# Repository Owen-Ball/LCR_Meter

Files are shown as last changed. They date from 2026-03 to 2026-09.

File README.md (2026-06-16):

A DIY LCR meter capable of

1pF to 10mF
1uH to 100H
1mΩ to 1MΩ

(actual ranges to be confirmed)

Many thanks to the work of WeTec/wschuma. Much of the audio codec design and firmware was based on their work on EEVblog and Github
https://www.eevblog.com/forum/projects/teensylcr-a-teensy-based-diy-lcr-meter/
https://github.com/wschuma/TeensyLCR

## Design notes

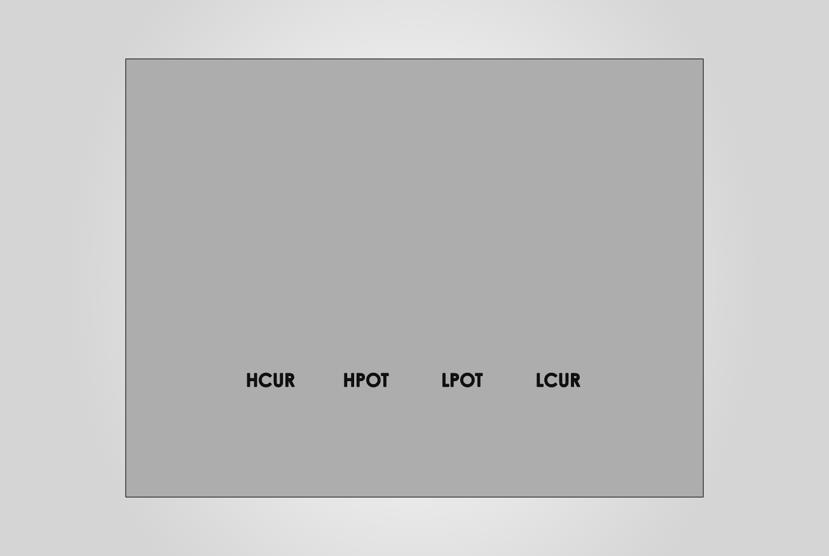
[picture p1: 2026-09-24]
CAD/STLs/front_panel.PNG

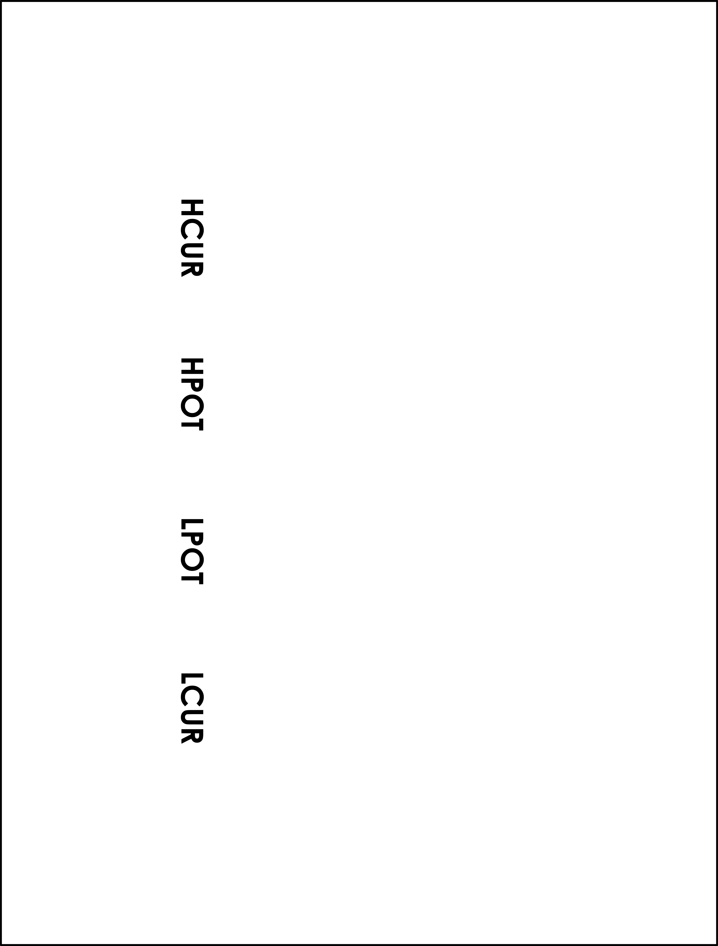
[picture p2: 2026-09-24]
CAD/STLs/bitmap.png

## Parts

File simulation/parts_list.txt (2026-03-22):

THS4561 - diff amps for driving ADCs
TLV354 - Signal buffer and TIA
OPA365 - PGA

To Do
-resistor sizing for PGA
-sim PGA
-add second diff amp
-stability at 100k?

-protection circuit
-power

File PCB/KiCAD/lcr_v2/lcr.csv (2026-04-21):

Reference | Qty | Value | DNP | Exclude from BOM | Exclude from Board | Footprint | Datasheet
BZ1 | 1 | Buzzer |  |  |  | Buzzer_Beeper:Buzzer_12x9.5RM7.6
C1,C2,C16,C17,C20,C21,C22,C24,C25,C26 | 10 | C |  |  |  | Capacitor_SMD:C_0805_2012Metric
C3,C4,C28,C29 | 4 | 470p |  |  |  | Capacitor_SMD:C_0805_2012Metric
C5,C30 | 2 | 2.7n |  |  |  | Capacitor_SMD:C_0805_2012Metric
C6,C9,C47,C49 | 4 | 1u |  |  |  | Capacitor_SMD:C_0805_2012Metric
C7,C8,C46,C48 | 4 | .1u |  |  |  | Capacitor_SMD:C_0805_2012Metric
C10,C27,C34,C35,C36,C37,C38,C39,C40,C41,C42,C43,C45,C50,C51 | 15 | 100n |  |  |  | Capacitor_SMD:C_0805_2012Metric
C11,C13,C31 | 3 | 100p |  |  |  | Capacitor_SMD:C_0805_2012Metric
C12 | 1 | 220p |  |  |  | Capacitor_SMD:C_0805_2012Metric
C14,C15 | 2 | 33p |  |  |  | Capacitor_SMD:C_0805_2012Metric
C18,C19,C23,C44 | 4 | 47u |  |  |  | Capacitor_SMD:CP_Elec_5x5.9
C33 | 1 | 10u |  |  |  | Capacitor_SMD:C_0805_2012Metric
D3,D4,D5 | 3 | D_Schottky |  |  |  | Diode_SMD:Nexperia_CFP3_SOD-123W
D6 | 1 | D_Schottky |  |  |  | Diode_SMD:D_0805_2012Metric
D8,D9,D10,D11 | 4 | ESD7205 |  |  |  | Package_TO_SOT_SMD:SOT-323_SC-70
F1,F2,F3,F4 | 4 | 1206L012WR |  |  |  | Fuse:Fuse_1206_3216Metric
J1,J2,J3,J4 | 4 | Conn_Coaxial |  |  |  | Connector_Coaxial:BNC_Amphenol_B6252HB-NPP3G-50_Horizontal
J5 | 1 | Conn_01x06_Pin |  |  |  | Connector_PinHeader_2.54mm:PinHeader_1x06_P2.54mm_Vertical
J6 | 1 | Screw_Terminal_01x02 |  |  |  | TerminalBlock_Phoenix:TerminalBlock_Phoenix_MKDS-1,5-2-5.08_1x02_P5.08mm_Horizontal
J7 | 1 | Barrel_Jack_Switch |  |  |  | Connector_BarrelJack:BarrelJack_GCT_DCJ200-10-A_Horizontal
J8 | 1 | Conn_01x09_Pin |  |  |  | Connector_PinHeader_2.54mm:PinHeader_1x09_P2.54mm_Vertical
J9 | 1 | Conn_01x14_Pin |  |  |  | Connector_PinHeader_2.54mm:PinHeader_1x14_P2.54mm_Vertical
J10 | 1 | Conn_01x02_Pin |  |  |  | Connector_PinHeader_2.54mm:PinHeader_1x02_P2.54mm_Vertical
JP1 | 1 | Jumper_2_Open |  |  |  | Connector_PinHeader_2.54mm:PinHeader_1x02_P2.54mm_Vertical
Q1,Q2 | 2 | DMG1012UWQ-7 |  |  |  | Package_TO_SOT_SMD:SOT-323_SC-70
R1,R8,R21,R24,R44,R48 | 6 | 8.2k |  |  |  | Resistor_SMD:R_0805_2012Metric
R2,R7,R45,R49 | 4 | 1.6k |  |  |  | Resistor_SMD:R_0805_2012Metric
R3,R6,R46,R50 | 4 | 300 |  |  |  | Resistor_SMD:R_0805_2012Metric
R4,R5,R31,R35,R47,R51,R60,R63,R64 | 9 | 100 |  |  |  | Resistor_SMD:R_0805_2012Metric
R9,R10,R17,R41 | 4 | 1M |  |  |  | Resistor_SMD:R_0805_2012Metric
R13,R14,R15,R30,R34,R36,R42,R52,R53,R54,R55 | 11 | 1k |  |  |  | Resistor_SMD:R_0805_2012Metric
R16,R18,R56,R57 | 4 | 22 |  |  |  | Resistor_SMD:R_0805_2012Metric
R19,R20 | 2 | 5.1k |  |  |  | Resistor_SMD:R_0805_2012Metric
R22,R23,R29,R37,R43,R58,R59,R61,R62,R65 | 10 | 10k |  |  |  | Resistor_SMD:R_0805_2012Metric
R25,R26 | 2 | 3.3k |  |  |  | Resistor_SMD:R_0805_2012Metric
R27,R32,R33,R39,R40 | 5 | R_US |  |  |  | Resistor_SMD:R_0805_2012Metric
R28,R38 | 2 | 100k |  |  |  | Resistor_SMD:R_0805_2012Metric
R66 | 1 | 0 |  |  |  | Resistor_SMD:R_0805_2012Metric
SW1 | 1 | SW_SPST |  |  |  | Connector_PinHeader_2.54mm:PinHeader_1x02_P2.54mm_Vertical
TP1,TP2,TP3,TP4,TP5,TP6,TP7,TP8,TP9,TP10,TP11,TP12,TP13,TP14,TP15,TP16 | 16 | TestPoint |  |  |  | Others:testpoint_0805
U1,U13 | 2 | OPA2365AIDR |  |  |  | Package_SO:SOIC-8_3.9x4.9mm_P1.27mm
U2,U15 | 2 | THS4561IDGKR |  |  |  | Package_SO:TSSOP-8_3x3mm_P0.65mm | https://www.ti.com/lit/ds/symlink/ths4561.pdf?HQS=dis-dk-null-digikeymode-dsf-pf-null-wwe&ts=1774136984154
U3 | 1 | CS4272 |  |  |  | Package_SO:TSSOP-28_4.4x9.7mm_P0.65mm | https://statics.cirrus.com/pubs/proDatasheet/CS4272_F1.pdf
U4,U14 | 2 | DG4052EEQ |  |  |  | Package_SO:TSSOP-16_4.4x5mm_P0.65mm
U5 | 1 | Teensy4.1_mainpins |  |  |  | Teensy:Teensy41_mainpins
U6 | 1 | MCP9800Ax-xOT |  |  |  | Package_TO_SOT_SMD:SOT-23-5 | https://ww1.microchip.com/downloads/aemDocuments/documents/OTH/ProductDocuments/DataSheets/21909d.pdf
U7,U16 | 2 | TLV9161IDBVR |  |  |  | Package_TO_SOT_SMD:SOT-23-5
U9,U12 | 2 | DG2034EDQ |  |  |  | Others:MSOP-10_largecorner
U10,U11 | 2 | MC7805 |  |  |  | Package_TO_SOT_SMD:TO-252-2 | http://www.st.com/content/ccc/resource/technical/document/datasheet/41/4f/b3/b0/12/d4/47/88/CD00000444.pdf/files/CD00000444.pdf/jcr:content/translations/en.CD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
U17 | 1 | TLV9162IDR |  |  |  | Package_SO:SOIC-8_3.9x4.9mm_P1.27mm
Y1 | 1 | Crystal |  |  |  | Crystal:Crystal_SMD_ECS_CSM3X-2Pin_7.6x4.1mm

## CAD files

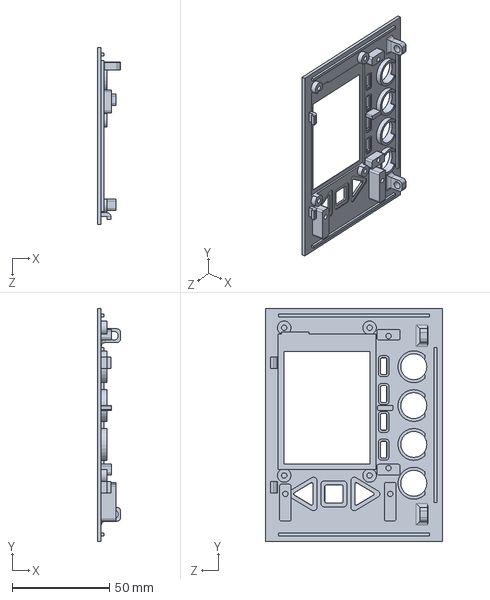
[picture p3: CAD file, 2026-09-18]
CAD/laser_assembly.SLDASM
12.0 x 120.0 x 91.0 mm

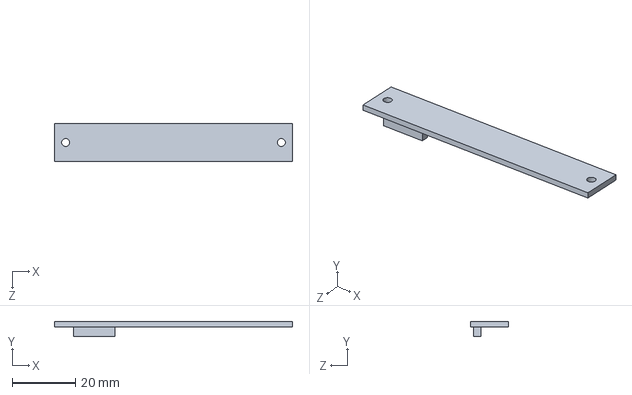
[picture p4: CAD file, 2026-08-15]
CAD/menu_assembly/menu_PCB.SLDPRT
75.0 x 4.60 x 12.0 mm

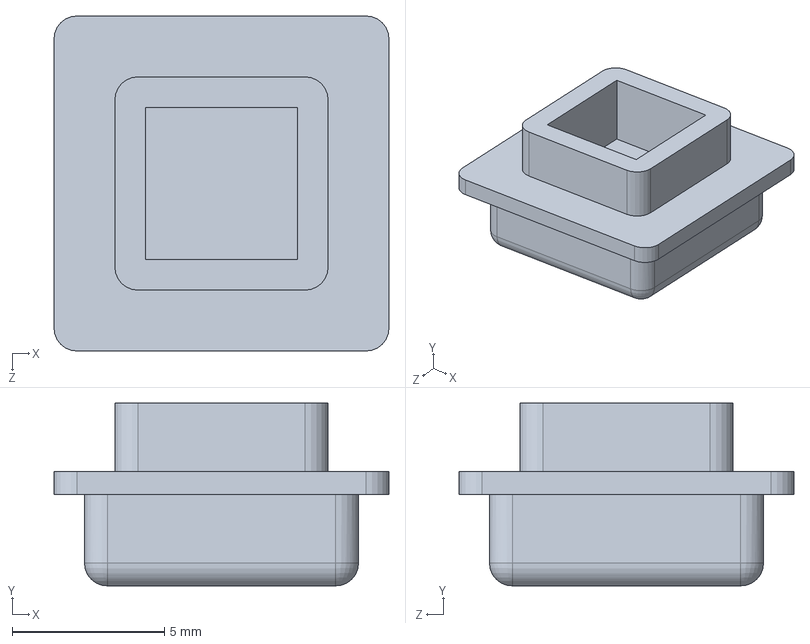
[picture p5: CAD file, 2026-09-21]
CAD/selector_assembly/enter_cap.SLDPRT
11.0 x 6.00 x 11.0 mm

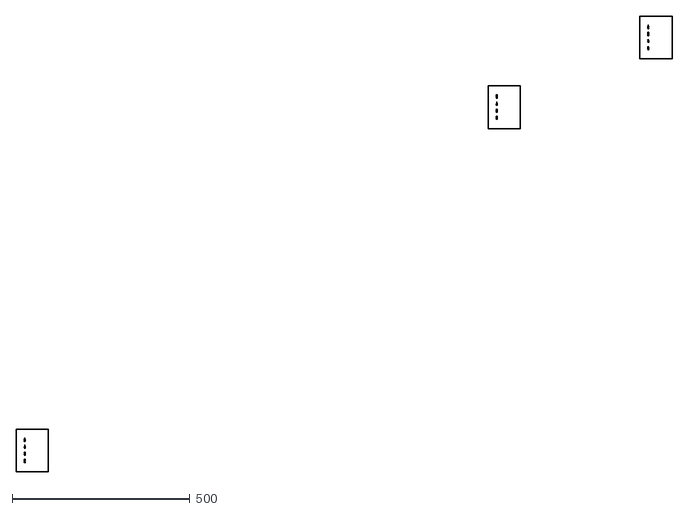
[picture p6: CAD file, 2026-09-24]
CAD/STLs/front_panel2.dxf
1845.1 x 1281.0

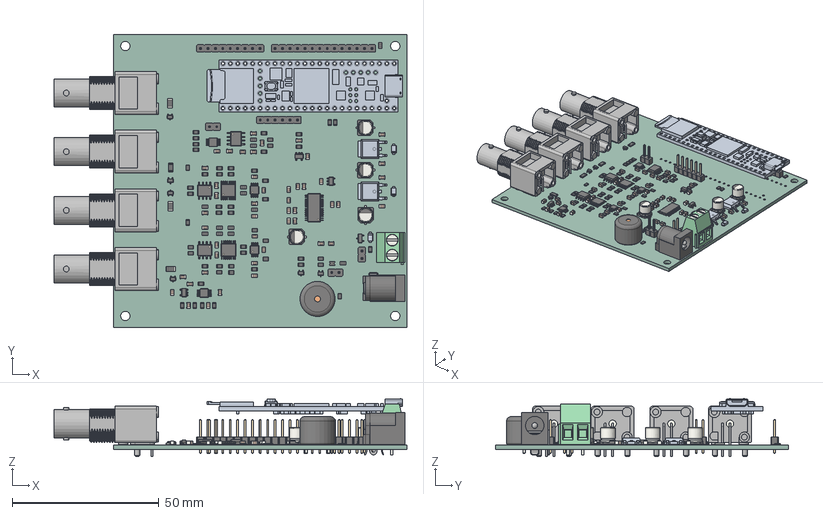
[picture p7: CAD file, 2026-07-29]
PCB/KiCAD/lcr_v2/.step
120.3 x 100.0 x 19.9 mm
R_0805_2012Metric x 65
C_0805_2012Metric x 47
SOT-23-5 x 3
TerminalBlock_Phoenix_MKDS-1,5-2-5.08_1x02_P5.08mm_Horizontal
TSSOP-8_3x3mm_P0.65mm x 2
PinHeader_1x06_P2.54mm_Vertical
.step 1.20.1 x 2
BNC_Amphenol_B6252HB-NPP3G-50_Horizontal x 4
BarrelJack_GCT_DCJ200-10-A_Horizontal
SOT-323_SC-70 x 6
PinHeader_1x02_P2.54mm_Vertical x 3
TSSOP-28_4.4x9.7mm_P0.65mm
.step 1.35.1 x 3
CP_Elec_5x5.9 x 4
Teensy_4.1_Assembly
MSOP-10_3x3mm_P0.5mm x 2
TSSOP-16_4.4x5mm_P0.65mm x 2
SOT-23
SOIC-8_3.9x4.9mm_P1.27mm x 3
D_0805_2012Metric
Fuse_1206_3216Metric x 4
Buzzer_12x9.5RM7.6
PinHeader_1x09_P2.54mm_Vertical
PinHeader_1x14_P2.54mm_Vertical
lcr_PCB

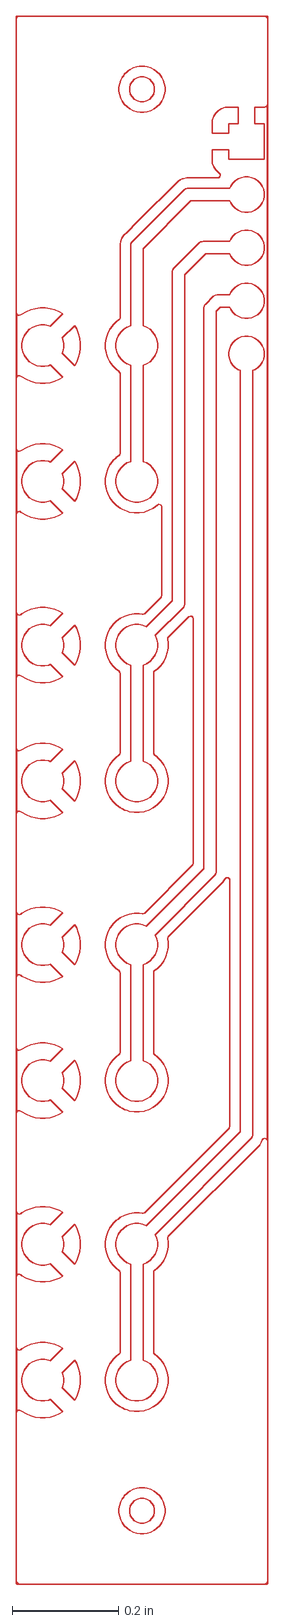
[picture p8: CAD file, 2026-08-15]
PCB/KiCAD/menu_board/menu_board/menu_board-F_Cu.dxf
0.473 x 2.95 in

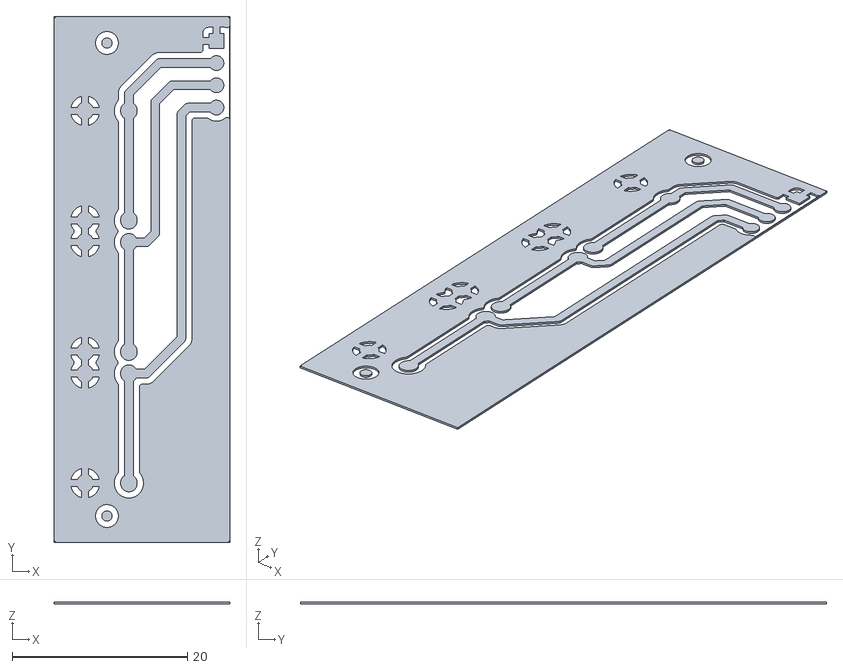
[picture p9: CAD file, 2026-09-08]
PCB/KiCAD/selector_board/selector_board/selector_board.stl
20.1 x 60.0 x 0.2

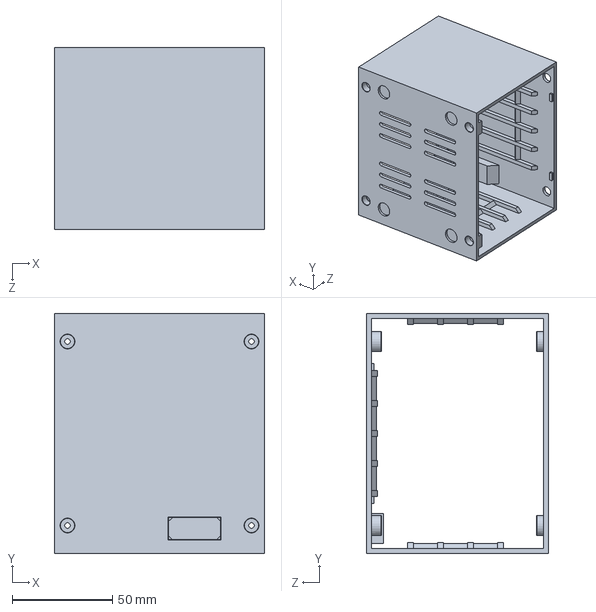
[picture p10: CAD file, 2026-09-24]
CAD/shell.SLDPRT
105.0 x 120.0 x 91.0 mm

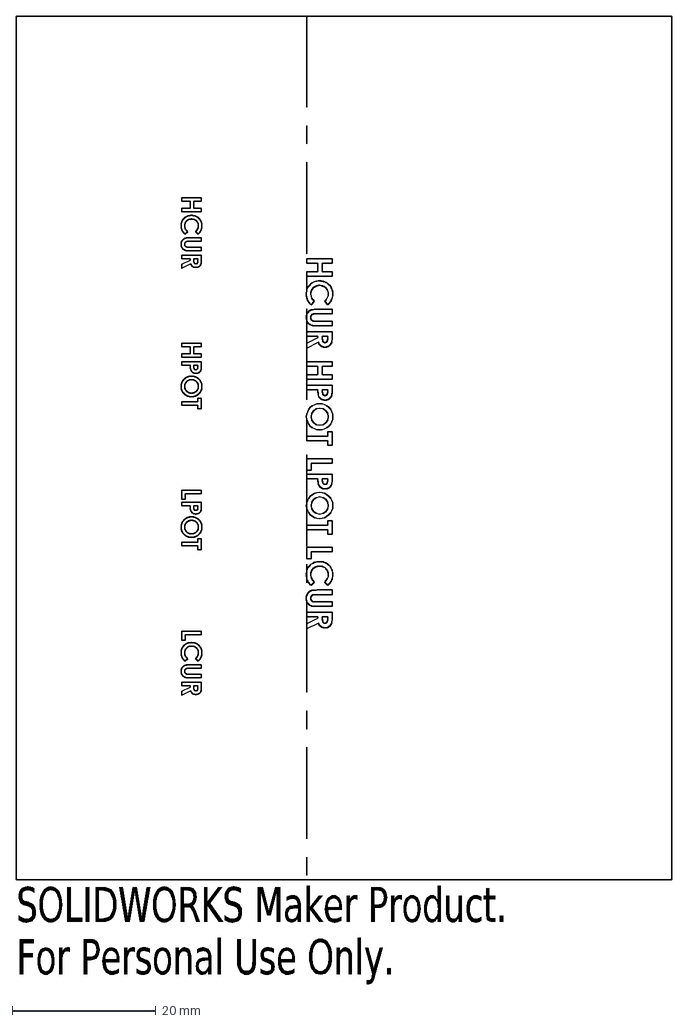
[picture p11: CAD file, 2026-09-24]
CAD/STLs/front_panel5.DXF
SOLIDWORKS Maker Product.
For Personal Use Only.

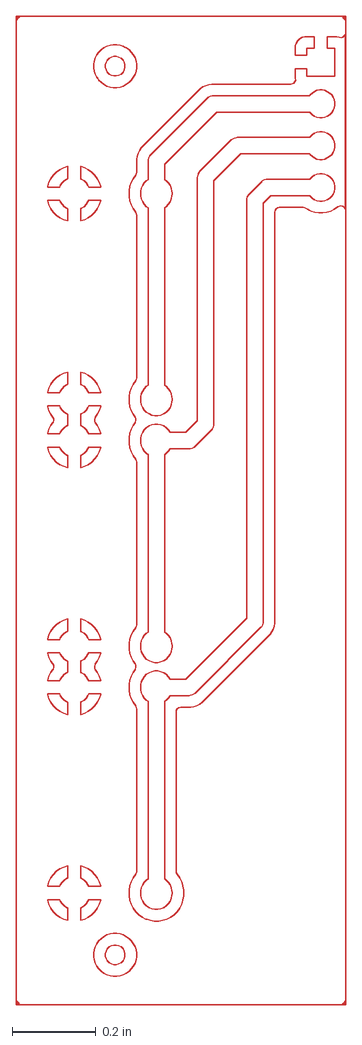
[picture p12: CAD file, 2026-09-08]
PCB/KiCAD/selector_board/selector_board/selector_board-F_Cu.dxf
0.789 x 2.36 in

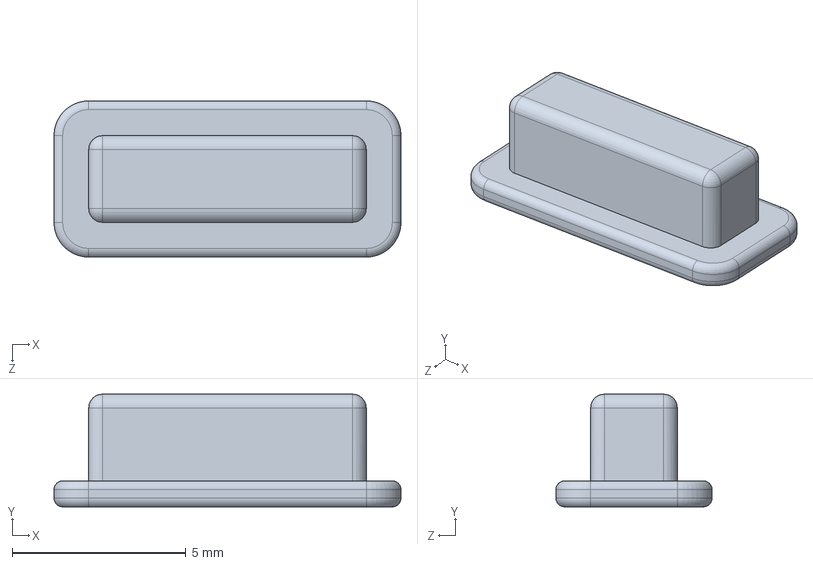
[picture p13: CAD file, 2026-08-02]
CAD/menu_assembly/menu_buttons.SLDPRT
10.0 x 3.25 x 4.50 mm

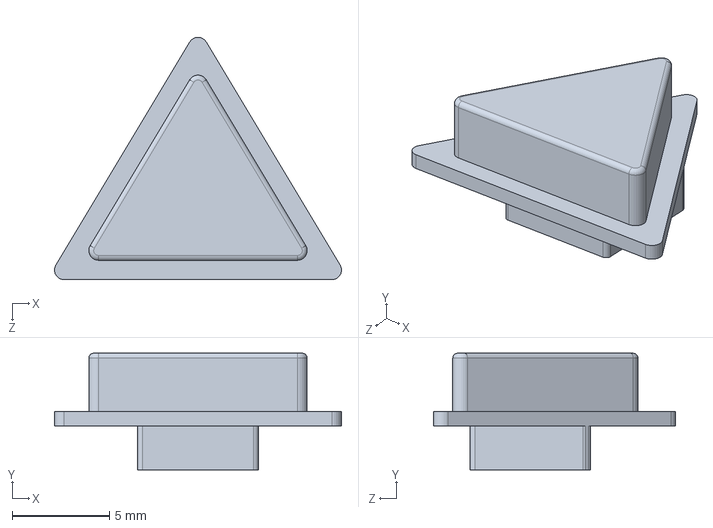
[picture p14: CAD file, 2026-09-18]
CAD/selector_assembly/arrow_cap.SLDPRT
14.8 x 6.00 x 12.5 mm

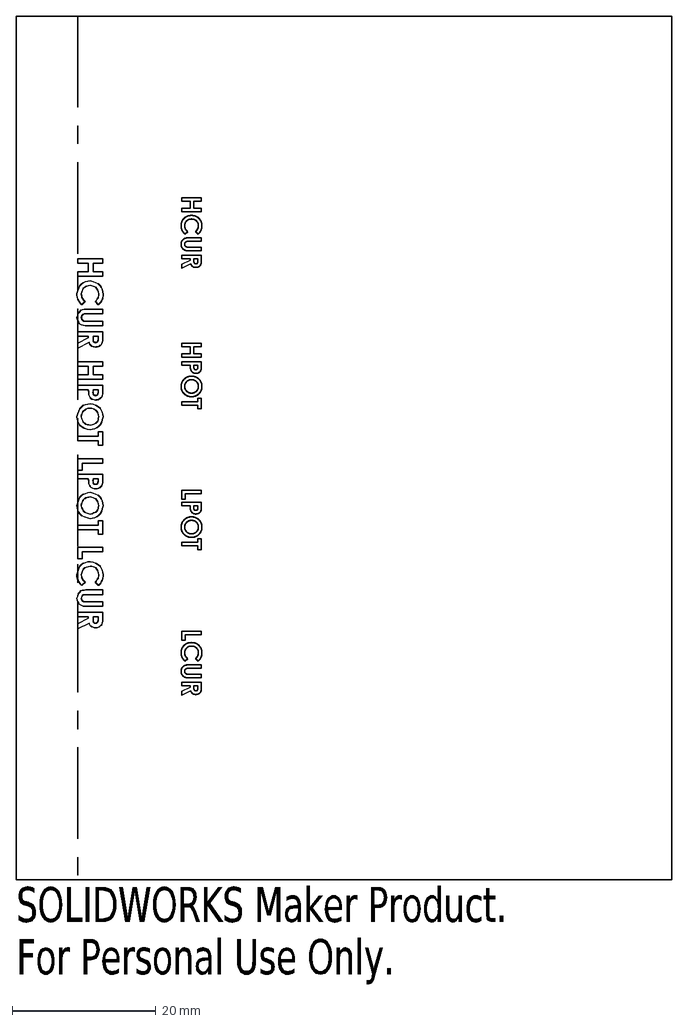
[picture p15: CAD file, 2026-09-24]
CAD/STLs/front_panel4.DXF
SOLIDWORKS Maker Product.
For Personal Use Only.

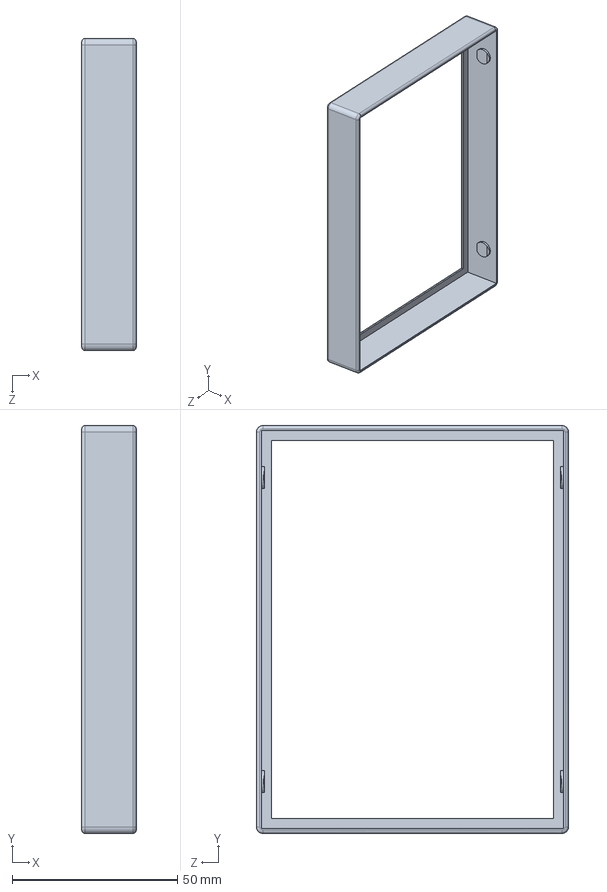
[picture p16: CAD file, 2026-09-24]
CAD/trim.SLDPRT
16.5 x 123.4 x 94.4 mm

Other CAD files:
CAD/menu_assembly/menu_assembly.SLDASM
CAD/selector_assembly/selector_assembly.SLDASM
CAD/front_panel.SLDPRT
CAD/m3_spacer.SLDPRT
CAD/2.8 TFT Module.SLDASM
CAD/2.8 TFT Module.stp
CAD/STLs/back_panel.STL
CAD/STLs/compartment_lid.STL
CAD/STLs/enter_cap - arrow_cap-1.STL
CAD/STLs/enter_cap - arrow_cap-2.STL
CAD/STLs/enter_cap - button-1.STL
CAD/STLs/enter_cap - button-2.STL
CAD/STLs/enter_cap - button-3.STL
CAD/STLs/enter_cap - enter_cap-1.STL
CAD/STLs/enter_cap - pcb-1.STL
CAD/STLs/enter_cap.STL
CAD/STLs/front_panel.3MF
CAD/STLs/front_panel.DXF
CAD/STLs/front_panel.STL
CAD/STLs/front_panel3.DXF
CAD/STLs/m3_spacer.STL
CAD/STLs/shell.STL
CAD/STLs/trim.3mf
CAD/STLs/trim.STL
CAD/TFT_2p8.step
CAD/TFT_glass.SLDPRT
CAD/back_panel.SLDPRT
CAD/compartment_lid.SLDPRT
CAD/laser_jig.SLDPRT
CAD/menu_assembly/tactileswitch-short.SLDPRT
CAD/selector_assembly/button.SLDPRT
CAD/selector_assembly/pcb.SLDPRT
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

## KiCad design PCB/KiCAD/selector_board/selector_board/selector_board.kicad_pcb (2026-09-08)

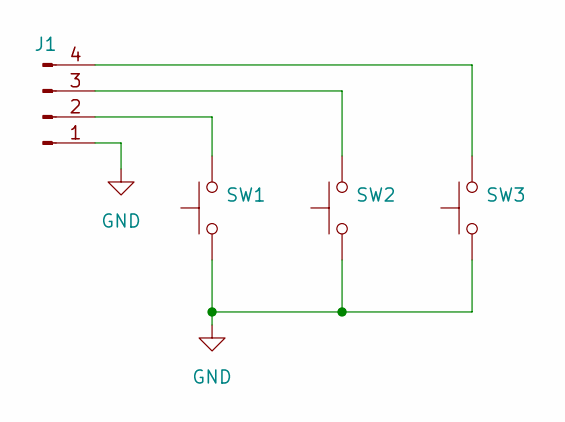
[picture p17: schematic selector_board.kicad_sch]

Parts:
J1: Conn_01x04_Pin; PinHeader_1x04_P2.54mm_Vertical
SW1, SW2, SW3: SW_Push; SW_PUSH-12mm

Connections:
GND: J1.1, SW1.1, SW2.1, SW3.1
unnamed: J1.2, SW1.2
unnamed: J1.3, SW2.2
unnamed: J1.4, SW3.2

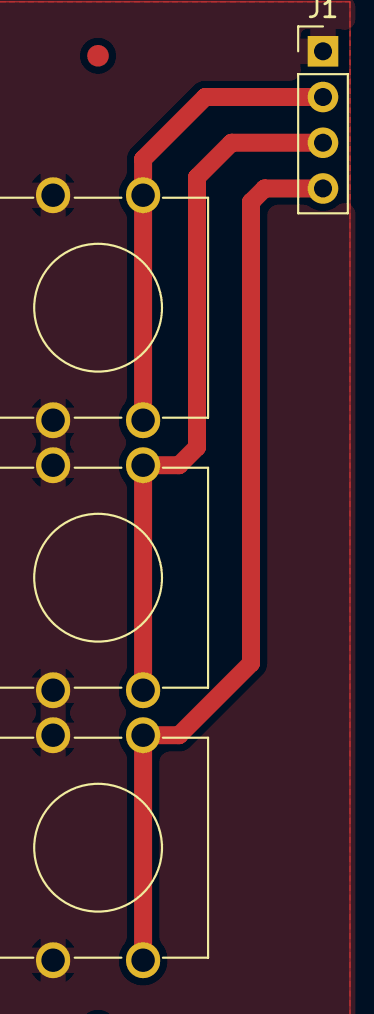
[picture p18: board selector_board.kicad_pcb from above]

Board: 2 copper layers, 4 parts (0 on the bottom side), 4 nets.

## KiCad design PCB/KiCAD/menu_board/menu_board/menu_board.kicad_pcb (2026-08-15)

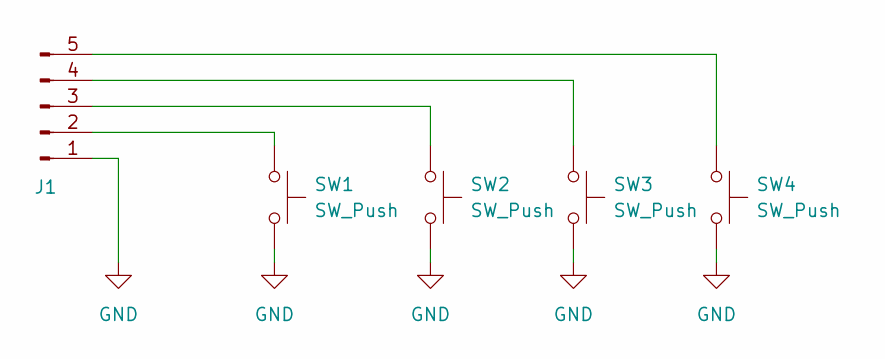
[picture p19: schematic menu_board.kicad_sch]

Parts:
J1: Conn_01x05_Pin; PinHeader_1x05_P2.54mm_Vertical
SW1, SW2, SW3, SW4: SW_Push; SW_PUSH_6mm

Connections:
GND: J1.1, SW1.2, SW2.2, SW3.2, SW4.2
unnamed: J1.2, SW1.1
unnamed: J1.3, SW2.1
unnamed: J1.4, SW3.1
unnamed: J1.5, SW4.1

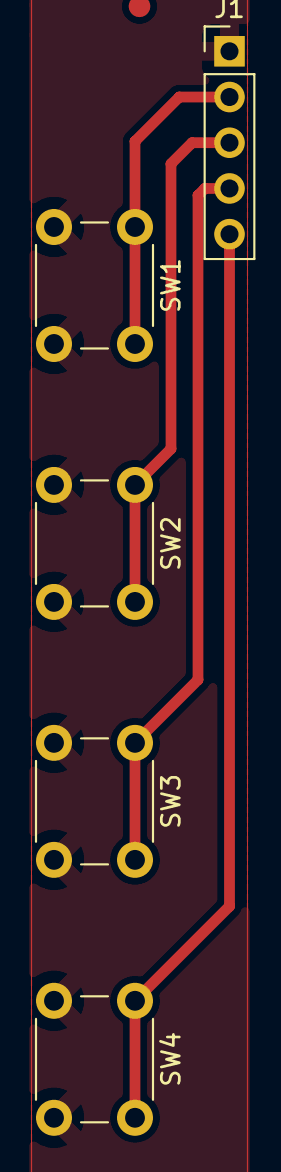
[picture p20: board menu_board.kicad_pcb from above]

Board: 2 copper layers, 5 parts (0 on the bottom side), 5 nets.

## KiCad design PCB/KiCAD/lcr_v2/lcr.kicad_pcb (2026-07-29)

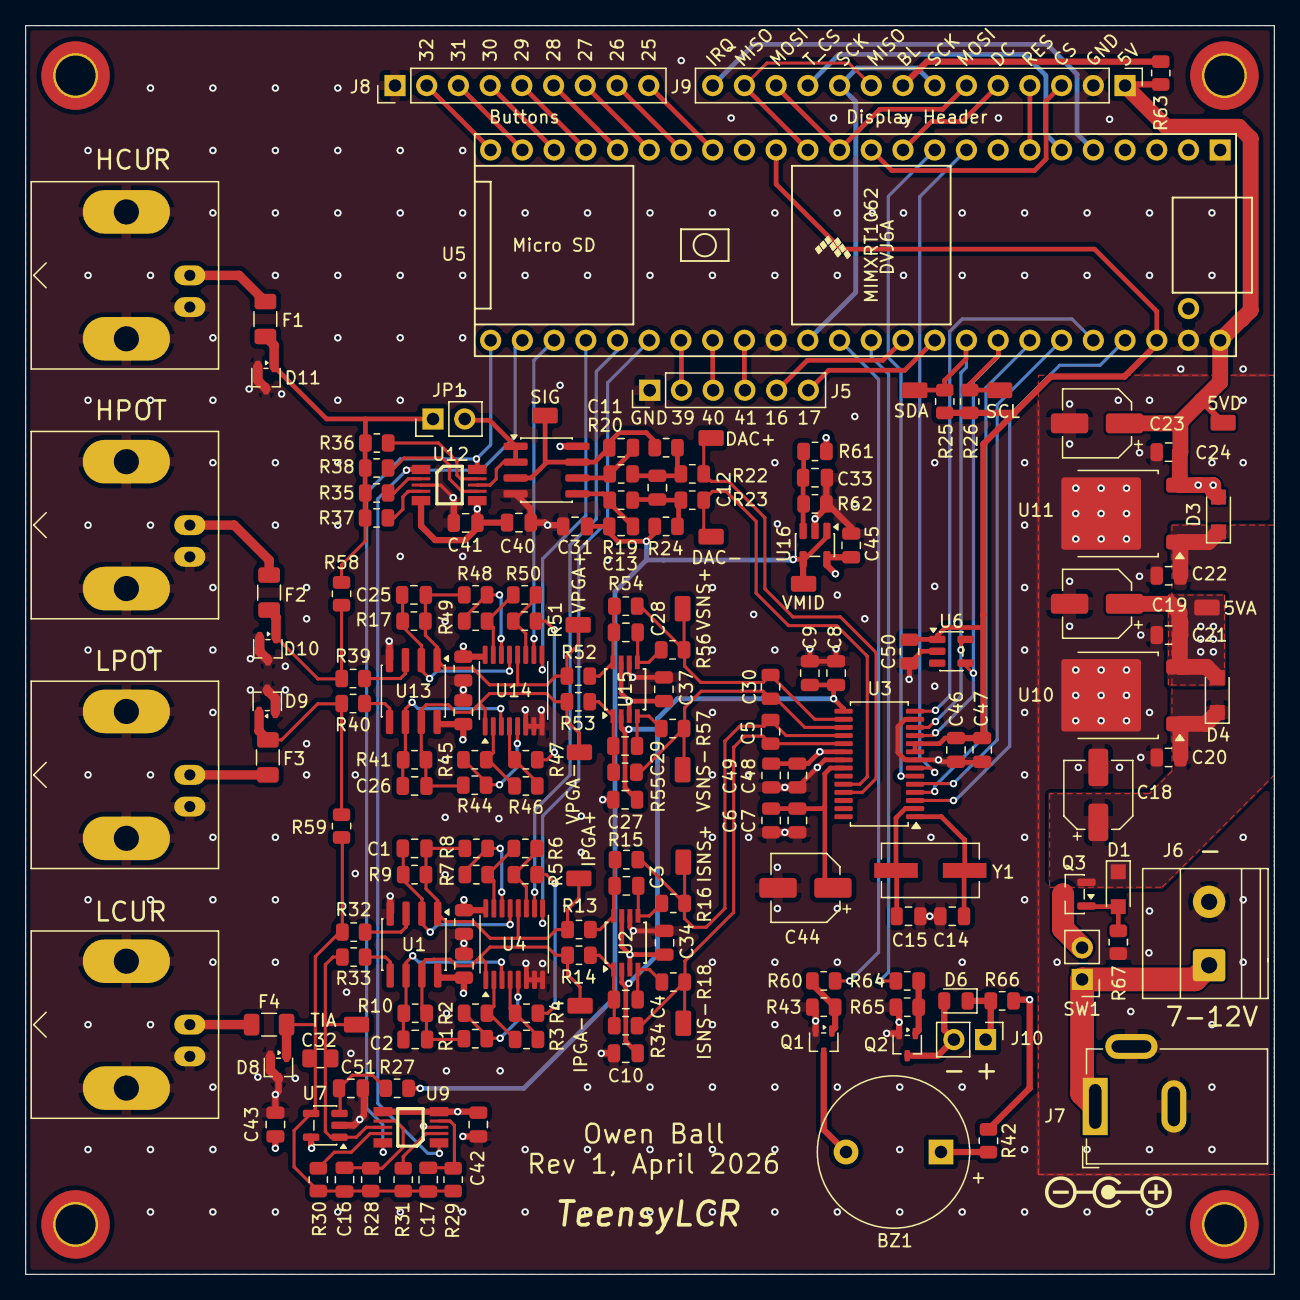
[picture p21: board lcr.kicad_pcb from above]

Board: 4 copper layers, 100.0 x 100.0 mm, 182 parts (0 on the bottom side), 122 nets.

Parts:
BZ1: Buzzer; Buzzer_12x9.5RM7.6
C1, C2, C16, C17, C25, C26, C32: 1p; C_0805_2012Metric
C3, C4, C28, C29: 470p; C_0805_2012Metric
C5, C30: 2.7n; C_0805_2012Metric
C6, C9, C20, C21, C22, C24, C47, C49: 1u; C_0805_2012Metric
C7, C8, C46, C48: .1u; C_0805_2012Metric
C10, C27, C34, C35, C36, C37, C38, C39, C40, C41, C42, C43, C45, C50, C51: 100n; C_0805_2012Metric
C11, C13, C31: 100p; C_0805_2012Metric
C12: 220p; C_0805_2012Metric
C14, C15: 33p; C_0805_2012Metric
C18, C19, C23, C44: 47u; CP_Elec_5x5.9
C33: 10u; C_0805_2012Metric
D1: 7.5V; Nexperia_CFP3_SOD-123W
D3, D4: D_Schottky; Nexperia_CFP3_SOD-123W
D6: D_Schottky; D_0805_2012Metric
D8, D9, D10, D11: ESD7205; SOT-323_SC-70
F1, F2, F3, F4: 1206L012WR; Fuse_1206_3216Metric
H1, H2, H3, H4: MountingHole_Pad; MountingHole_3.2mm_M3_ISO14580_Pad_TopBottom
J1, J2, J3, J4: Conn_Coaxial; BNC_Amphenol_B6252HB-NPP3G-50_Horizontal
J5: Conn_01x06_Pin; PinHeader_1x06_P2.54mm_Vertical
J6: Screw_Terminal_01x02; TerminalBlock_Phoenix_MKDS-1,5-2-5.08_1x02_P5.08mm_Horizont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
J7: Barrel_Jack_Switch; BarrelJack_GCT_DCJ200-10-A_Horizontal
J8: Conn_01x09_Pin; PinHeader_1x09_P2.54mm_Vertical
J9: Conn_01x14_Pin; PinHeader_1x14_P2.54mm_Vertical
J10: Conn_01x02_Pin; PinHeader_1x02_P2.54mm_Vertical
JP1: Jumper_2_Open; PinHeader_1x02_P2.54mm_Vertical
Q1, Q2: DMG1012UWQ-7; SOT-323_SC-70
Q3: DMP3099L; SOT-23
R1, R8, R21, R24, R44, R48: 8.2k; R_0805_2012Metric
R2, R7, R45, R49: 1.6k; R_0805_2012Metric
R3, R6, R46, R50: 300; R_0805_2012Metric
R4, R5, R31, R35, R47, R51, R60, R63, R64: 100; R_0805_2012Metric
R9, R10, R17, R41: 1M; R_0805_2012Metric
R13, R14, R15, R30, R34, R36, R42, R52, R53, R54, R55: 1k; R_0805_2012Metric
R16, R18, R56, R57: 22; R_0805_2012Metric
R19, R20: 5.1k; R_0805_2012Metric
R22, R23, R29, R37, R43, R58, R59, R61, R62, R65: 10k; R_0805_2012Metric
R25, R26: 3.3k; R_0805_2012Metric
R27: R_US; R_0805_2012Metric
R28, R38, R67: 100k; R_0805_2012Metric
R32, R33, R39, R40, R66: 0; R_0805_2012Metric
SW1: SW_SPST; PinHeader_1x02_P2.54mm_Vertical
TP1: ISNS+; testpoint_0805
TP2: ISNS-; testpoint_0805
TP3: VSNS+; testpoint_0805
TP4: VSNS-; testpoint_0805
TP5: DAC+; testpoint_0805
TP6: DAC-; testpoint_0805
TP7: SIG; testpoint_0805
TP8: IPGA+; testpoint_0805
TP9: IPGA-; testpoint_0805
TP10: VPGA-; testpoint_0805
TP11: VPGA+; testpoint_0805
TP12: 5VA; testpoint_0805
TP13: 5VD; testpoint_0805
TP14: SCL; testpoint_0805
TP15: SDA; testpoint_0805
TP16: TIA; testpoint_0805
TP17: VMID; testpoint_0805
U1, U13: OPA2365AIDR; SOIC-8_3.9x4.9mm_P1.27mm
U2, U15: THS4561IDGKR; TSSOP-8_3x3mm_P0.65mm
U3: CS4272; TSSOP-28_4.4x9.7mm_P0.65mm
U4, U14: DG4052EEQ; TSSOP-16_4.4x5mm_P0.65mm
U5: Teensy4.1_mainpins; Teensy41_mainpins
U6: MCP9800Ax-xOT; SOT-23-5
U7, U16: TLV9161IDBVR; SOT-23-5
U9, U12: DG2034EDQ; MSOP-10_largecorner
U10, U11: MC7805; TO-252-2
U17: TLV9162IDR; SOIC-8_3.9x4.9mm_P1.27mm
Y1: Crystal; Crystal_SMD_ECS_CSM3X-2Pin_7.6x4.1mm

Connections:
+3.3V: C46.2, C47.2, C50.2, R25.1, R26.1, U3.9 (VD), U3.10 (VL), U5.15 (3V3), U5.46 (3V3), U6.1 (V_{DD})
+5VA: C19.1, C21.1, C34.2, C35.2, C36.2, C37.2, C38.2, C39.2, C40.2, C41.2, C42.2, C43.2, C45.2, C48.2, C49.2, D4.2 (A), R61.1, TP12.1 (1_1), U1.8 (V+), U2.3 (V_{S+}), U2.7 (~PD), U3.20 (VA), U4.16 (V+), U7.5 (V+), U9.5 (EN), U9.6 (V+), U10.3 (OUT), U12.5 (EN), U12.6 (V+), U13.8 (V+), U14.16 (V+), U15.3 (V_{S+}), U15.7 (~PD), U16.5 (V+), U17.8 (V+)
+5VD: C23.1, C24.1, D3.2 (A), J9.1, R42.1, R63.1, R66.1, TP13.1 (1_1), U5.48 (VIN), U11.3 (OUT)
+12V: C18.1, C20.1, C22.1, D1.1 (K), D3.1 (K), D4.1 (K), Q3.2 (S), U10.1 (IN), U11.1 (IN)
/BTN1: J8.9, U5.17 (25_A11_RX6_SDA2)
/BTN2: J8.8, U5.18 (26_A12_MOSI1)
/BTN3: J8.7, U5.19 (27_A13_SCK1)
/BTN4: J8.6, U5.20 (28_RX7)
/BTN5: J8.5, U5.21 (29_TX7)
/BTN6: J8.4, U5.22 (30_CRX3)
/BTN7: J8.3, U5.23 (31_CTX3)
/BTN8: J8.2, U5.24 (32_OUT1B)
/BUZZ: R60.1, U5.36 (14_A0_TX3_SPDIF_OUT)
/DISP_CS: J9.3, U5.12 (10_CS_MQSR)
/DISP_DC: J9.5, U5.11 (9_OUT1C)
/DISP_MISO: J9.9, J9.13, U5.14 (12_MISO_MQSL)
/DISP_MOSI: J9.6, J9.12, U5.13 (11_MOSI_CTX1)
/DISP_RESET: J9.4, U5.7 (5_IN2)
/DISP_SCK: J9.7, J9.10, U5.35 (13_SCK_LED)
/DISP_T_CS: J9.11, U5.6 (4_BCLK2)
/DISP_T_IRQ: J9.14, U5.5 (3_LRCLK2)
/FAN_PWM: R64.1, U5.37 (15_A1_RX3_SPDIF_IN)
/GPIO1: J5.6, U5.39 (17_A3_TX4_SDA1)
/GPIO2: J5.5, U5.38 (16_A2_RX4_SCL1)
/GPIO3: J5.4, U5.33 (41_A17)
/GPIO4: J5.3, U5.32 (40_A16)
/GPIO5: J5.2, U5.31 (39_MISO1_OUT1A)
/TIA_FB: C16.1, C17.1, C32.1, D8.1 (K), F4.2, R28.2, R29.2, R30.2, R31.2, R32.2, R59.2, U7.4 (-)
/TIA_OUT: C32.2, R33.2, TP16.1 (1_1), U7.1, U9.8 (COM)
/sig_buf: JP1.2 (B), U12.8 (COM), U17.1, U17.2 (-)
/sig_conn: D11.1 (K), F1.2, JP1.1 (A), R35.2, R36.2, R37.2, R38.2, R58.1
BCLK: U3.5 (SCLK), U5.43 (21_A7_RX5_BCLK1)
CODEC_RST: U3.14 (~RST), U5.44 (22_A8_CTX1)
GND: C6.1, C7.1, C8.1, C9.1, C10.1, C14.2, C15.2, C18.2, C19.2, C20.2, C21.2, C22.2, C23.2, C24.2, C27.1, C31.2, C33.2, C34.1, C35.1, C36.1, C37.1, C38.1, C39.1, C40.1, C41.1, C42.1, C43.1, C44.2, C45.1, C46.1, C47.1, C48.1, C49.1, C50.1, C51.1, D8.2 (K), D8.3 (A), D9.2 (K), D9.3 (A), D10.2 (K), D10.3 (A), D11.2 (K), D11.3 (A), J1.2 (Ext), J2.2 (Ext), J3.2 (Ext), J4.2 (Ext), J5.1, J6.2, J7.2, J7.3, J8.1, J9.2, Q1.2 (S), Q2.2 (S), R43.2, R62.2, R65.2, R67.2, U1.4 (V-), U2.6 (V_{S-}), U3.8 (DGND), U3.13 (AD0/~CS(I2S/~LJ)), U3.21 (AGND), U4.6 (EN), U4.7 (V-), U4.8 (GND), U5.1 (GND), U5.34 (GND), U5.47 (GND), U6.2 (GND), U7.2 (V-), U9.3 (V-), U10.2 (GND), U11.2 (GND), U12.3 (V-), U13.4 (V-), U14.6 (EN), U14.7 (V-), U14.8 (GND), U15.6 (V_{S-}), U16.2 (V-), U17.4 (V-)
ISNS_N: C5.1, R18.1, R34.1, TP2.1 (1_1), U3.19 (AINB-)
ISNS_P: C5.2, R15.2, R16.1, TP1.1 (1_1), U3.18 (AINB+)
LRCLK: U3.4 (LRCK), U5.42 (20_A6_TX5_LRCLK1)
MCLK: U3.3 (MCLK), U5.45 (23_A9_CRX1_MCLK1)
unnamed: BZ1.1 (+), R42.2
unnamed: BZ1.2 (-), Q1.3 (D)
unnamed: C3.2, R16.2, U2.5
unnamed: C4.2, R18.2, U2.4
unnamed: C12.1, R20.1, R21.1, R22.2
unnamed: C12.2, R19.1, R23.2, R24.2
unnamed: C28.2, R56.2, U15.5
unnamed: C29.2, R57.2, U15.4
unnamed: D1.2 (A), Q3.1 (G), R67.1
unnamed: D6.2 (A), J10.2, Q2.3 (D)
unnamed: D6.1 (K), J10.1, R66.2
unnamed: D9.1 (K), F3.2, R40.2, R59.1
unnamed: D10.1 (K), F2.2, R39.2, R58.2
unnamed: F1.1, J1.1 (In)
unnamed: F2.1, J2.1 (In)
unnamed: F3.1, J3.1 (In)
unnamed: F4.1, J4.1 (In)
unnamed: J6.1, J7.1, SW1.1 (A)
unnamed: J9.8, R63.2
unnamed: Q1.1 (G), R43.1, R60.2
unnamed: Q2.1 (G), R64.2, R65.1
unnamed: Q3.3 (D), SW1.2 (B)
unnamed: R4.2, R5.2
unnamed: R47.2, R51.2
unnamed: R32.1, U1.3 (+)
unnamed: C1.1, R9.2, U1.2 (-), U4.13 (X)
unnamed: R33.1, U1.5 (+)
unnamed: C2.1, R10.2, U1.6 (-), U4.3 (Y)
unnamed: C3.1, R13.1, R15.1, U2.8 (+)
unnamed: C4.1, R14.1, R34.2, U2.1 (-)
unnamed: R22.1, TP5.1 (1_1), U3.25 (AOUTA+)
unnamed: R23.1, TP6.1 (1_1), U3.24 (AOUTA-)
unnamed: C6.2, C7.2, C44.1, U3.22 (FILT+)
unnamed: C14.1, U3.1 (XT0), Y1.2
unnamed: C15.1, U3.2 (XTI), Y1.1
unnamed: C1.2, R8.1, R9.1, R13.2, TP8.1 (1_1), U1.1, U4.12 (X0)
unnamed: R7.1, R8.2, U4.14 (X1)
unnamed: R6.1, R7.2, U4.15 (X2)
unnamed: R5.1, R6.2, U4.11 (X3)
unnamed: C2.2, R1.1, R10.1, R14.2, TP9.1 (1_1), U1.7, U4.1 (Y0)
unnamed: R1.2, R2.1, U4.5 (Y1)
unnamed: R2.2, R3.1, U4.2 (Y2)
unnamed: R3.2, R4.1, U4.4 (Y3)
unnamed: C51.2, R27.1, U7.3 (+)
unnamed: R31.1, U9.2 (S1)
unnamed: R30.1, U9.9 (S2)
unnamed: C17.2, R29.1, U9.4 (S3)
unnamed: C16.2, R28.1, U9.7 (S4)
unnamed: R35.1, U12.2 (S1)
unnamed: R36.1, U12.9 (S2)
unnamed: R37.1, U12.4 (S3)
unnamed: R38.1, U12.7 (S4)
unnamed: R39.1, U13.3 (+)
unnamed: C25.1, R17.2, U13.2 (-), U14.13 (X)
unnamed: R40.1, U13.5 (+)
unnamed: C26.1, R41.2, U13.6 (-), U14.3 (Y)
unnamed: C25.2, R17.1, R48.1, R52.2, TP11.1 (1_1), U13.1, U14.12 (X0)
unnamed: R48.2, R49.1, U14.14 (X1)
unnamed: R49.2, R50.1, U14.15 (X2)
unnamed: R50.2, R51.1, U14.11 (X3)
unnamed: C26.2, R41.1, R44.1, R53.2, TP10.1 (1_1), U13.7, U14.1 (Y0)
unnamed: R44.2, R45.1, U14.5 (Y1)
unnamed: R45.2, R46.1, U14.2 (Y2)
unnamed: R46.2, R47.1, U14.4 (Y3)
unnamed: C28.1, R52.1, R54.2, U15.8 (+)
unnamed: C29.1, R53.1, R55.2, U15.1 (-)
unnamed: C33.1, R61.2, R62.1, U16.3 (+)
unnamed: C13.1, R19.2, U17.5 (+)
unnamed: C11.2, R20.2, U17.6 (-)
PGA_I_0: U4.10 (A), U5.29 (37_CS)
PGA_I_1: U4.9 (B), U5.30 (38_CS1_IN1)
PGA_V_0: U5.27 (35_TX8), U14.10 (A)
PGA_V_1: U5.28 (36_CS), U14.9 (B)
RSEL_0: U5.26 (34_RX8), U9.1 (A0), U12.1 (A0)
RSEL_1: U5.25 (33_MCLK2), U9.10 (A1), U12.10 (A1)
SCL: R26.2, TP14.1 (1_1), U3.11 (SCL/CCLK(M0)), U5.41 (19_A5_SCL), U6.4 (SCLK)
SDA: R25.2, TP15.1 (1_1), U3.12 (SDA/CDIN(M1)), U5.40 (18_A4_SDA), U6.5 (SDA)
SDIN: U3.6 (SDOUT(M/~S)), U5.10 (8_TX2_IN1)
SDOUT: U3.7 (SDIN), U5.9 (7_RX2_OUT1A)
SIG_OUT: C11.1, R21.2, TP7.1 (1_1), U17.3 (+), U17.7
VCOM: C8.2, C9.2, C10.2, C27.2, U2.2 (V_{OCM}), U3.15 (VCOM), U15.2 (V_{OCM})
VMID: C13.2, C31.1, R24.1, R27.2, TP17.1 (1_1), U16.1, U16.4 (-)
VSNS_N: C30.1, R55.1, R57.1, TP4.1 (1_1), U3.17 (AINA+)
VSNS_P: C30.2, R54.1, R56.1, TP3.1 (1_1), U3.16 (AINA-)

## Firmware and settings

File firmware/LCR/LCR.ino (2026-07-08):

#include <Audio.h>
#include <Wire.h>
#include <SPI.h>
#include <SD.h>
#include <SerialFlash.h>

#include "buzzer.h"
#include "board.h"
#include "codec.h"
#include "calibration.h"
#include "autorange.h"
#include "lcr_func.h"
#include "display.h"
#include "fsm.h"


long unsigned int loop_time = 0;
long unsigned int prev_time = 0;

void setup() {

  delay(500);

  Serial.begin(115200);
  
  board.init();
  codecInit();

  initDraw();
  initSystem();

  board.buzzer.runBuzzerBlocking(4, 10, 50);

  digitalWrite(FAN_PIN, HIGH);

  delay(100); 
}

void loop() {

  bool update_finished = !board.tft.asyncUpdateActive();
  
  runSystem();
  if (update_finished) {
    prev_time = micros();
    drawAll();
  }

  loop_time = micros() - prev_time;
  prev_time = micros();
  //Serial.println(loop_time);
}

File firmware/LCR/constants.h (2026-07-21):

#ifndef _CONSTANTS_
#define _CONSTANTS_


//BOARD PINS
#define PGA_V_0_PIN       35
#define PGA_V_1_PIN       36
#define PGA_I_0_PIN       37
#define PGA_I_1_PIN       38
#define RANGE_SEL_0_PIN   34
#define RANGE_SEL_1_PIN   33


#define BUZZER_PIN        14
#define FAN_PIN           15

#define TFT_CS            10
#define TFT_DC            9 
#define TFT_RST           5
#define TS_CS             4
#define TS_IRQ            3

#define ENTER_PIN         30       
#define UP_PIN            31
#define DOWN_PIN          29

#define BUTTON0_PIN       25
#define BUTTON1_PIN       26
#define BUTTON2_PIN       27
#define BUTTON3_PIN       28

//debounce time for all I/O buttons
#define DEBOUNCE_TIME_MS      50
//Takes N digital readings of each button, all must agree for output state to toggle
//Just some protection against noisy readings. Copied from my E-load code, don't know if it is needed here
#define BUTTON_AVG_COUNT      10


#define BUTTON_HOLD_BLANK     500
#define BUTTON_HOLD_DELAY     100

//RANGES
#define LCR_RANGE_100     0
#define LCR_RANGE_1K      1
#define LCR_RANGE_10K     2
#define LCR_RANGE_100K    3
#define LCR_RANGE_NUM     4


//PGA Gains
#define PGA_GAIN_1        0
#define PGA_GAIN_5        1
#define PGA_GAIN_25       2
#define PGA_GAIN_100      3
#define PGA_GAIN_NUM      4



#define LCR_MIN_FREQUENCY   100
#define MAX_DAC_AMPLITUDE   0.95
#define PGA_CAL_AMPLITUDE   0.8
#define DAC_OUTPUT_VPP      4.0


#define CODEC_CLIPPING_LEVEL        0.9
#define CODEC_SETTING_CHANGE_DELAY  500

//Time between autoranges. Removes chance of system not settling at new setting instantly
//and switching to another range
#define GAIN_AUTORANGE_DELAY        150
#define RANGE_AUTORANGE_DELAY       150


//Above this input peak value the board will attempt to drop the PGA gain if possible
#define AUTORANGE_LEVEL_HIGH        0.8
//Below this input peak value the board will attempt to raise the PGA gain. Must be >5x lower than high level
#define AUTORANGE_LEVEL_LOW         0.125

#define AUTORANGE_Z_LOW             0.25
#define AUTORANGE_Z_HIGH            4.00

//Unused currently, replaced by more detailed calibration procedure
#define I_PGA_GBWP    40e6
#define V_PGA_GBWP    40e6



#define LCR_FUNC_NUM  11


//set the resistor used to calibrate each range
//Didn't use 100 and 100k for the lower and upper ranges to avoid impact of probe parasitics
const float RANGE_CAL_RESISTOR[LCR_RANGE_NUM] = {1000, 1000, 10000, 10000};

const float RANGE_RESISTOR[LCR_RANGE_NUM] = {100, 1000, 10000, 100000};


#define V_CAL_RESISTOR    1000.0
#define I_CAL_RESISTOR    10000.0

#define Z_OVERFLOW        10e6

#define FILT_MAG_LIMIT    1.25




//DISPLAY CONSTANTS

#define DISP_REFRESH_TIME       100

#define SCREEN_WIDTH            320
#define SCREEN_HEIGHT           240

#define DISP_FLOAT_RANGE_UP     1.05
#define DISP_FLOAT_RANGE_DOWN   0.95

#define DISP_FLOAT_DECIMAL_HYST false

#define DISP_DIGITS             6

#define MENU_CATEGORY_HEIGHT    40
#define MENU_ITEM_HEIGHT        35


#define PROBE_BMP_X_POS         285
#define PROBE_BMP_Y_POS         10


#define SELECTOR_UP_Y_POS       70
#define SELECTOR_DOWN_Y_POS     155
#define SELECTOR_BUTTON_WIDTH   80
#define SELECTOR_BUTTON_HEIGHT  20
#define SELECTOR_COLOR          0xbdf7


#define POLARPLOT_X_POS         170
#define POLARPLOT_Y_POS         5
#define POLARPLOT_SIZE          80
#define POLARPLOT_MIN_EXP       -3
#define POLARPLOT_MAX_EXP       7
#define POLARPLOT_LABEL_INTERVAL 3

#define FREQSWEEP_MAX_POINTS    250
#define FREQSWEEP_WIDTH         180
#define FREQSWEEP_HEIGHT        120
#define FREQSWEEP_Y_OFFSET      -30
#define FREQSWEEP_PADDING       10
//Number of subdivisions per decade. 10 max
#define FREQSWEEP_DIVS_PER_DECADE 5

#define FREQSWEEP_START         100
#define FREQSWEEP_END           75000

//TOUCHSCREEN

#define TS_X_MIN                400
#define TS_X_MAX                3900
#define TS_Y_MIN                250
#define TS_Y_MAX                3750


#endif // _CONSTANTS_

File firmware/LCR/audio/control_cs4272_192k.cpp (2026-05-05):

#include <Arduino.h>
#include "control_cs4272_192k.h"
#include "Wire.h"

#define CS4272_ADDR 0x10

// Section 8.1 Mode Control
#define CS4272_MODE_CONTROL			(uint8_t)0x01
#define CS4272_MC_FUNC_MODE(x)			(uint8_t)(((x) & 0x03) << 6)
#define CS4272_MC_RATIO_SEL(x)			(uint8_t)(((x) & 0x03) << 4)
#define CS4272_MC_MASTER_SLAVE			(uint8_t)0x08
#define CS4272_MC_SERIAL_FORMAT(x)		(uint8_t)(((x) & 0x07) << 0)

// Section 8.2 DAC Control
#define CS4272_DAC_CONTROL			(uint8_t)0x02
#define CS4272_DAC_CTRL_AUTO_MUTE		(uint8_t)0x80
#define CS4272_DAC_CTRL_FILTER_SEL		(uint8_t)0x40
#define CS4272_DAC_CTRL_DE_EMPHASIS(x)		(uint8_t)(((x) & 0x03) << 4)
#define CS4272_DAC_CTRL_VOL_RAMP_UP		(uint8_t)0x08
#define CS4272_DAC_CTRL_VOL_RAMP_DN		(uint8_t)0x04
#define CS4272_DAC_CTRL_INV_POL(x)		(uint8_t)(((x) & 0x03) << 0)

// Section 8.3 DAC Volume and Mixing
#define CS4272_DAC_VOL				(uint8_t)0x03
#define CS4272_DAC_VOL_CH_VOL_TRACKING		(uint8_t)0x40
#define CS4272_DAC_VOL_SOFT_RAMP(x)		(uint8_t)(((x) & 0x03) << 4)
#define CS4272_DAC_VOL_ATAPI(x)			(uint8_t)(((x) & 0x0F) << 0)

// Section 8.4 DAC Channel A volume
#define CS4272_DAC_CHA_VOL			(uint8_t)0x04
#define CS4272_DAC_CHA_VOL_MUTE			(uint8_t)0x80
#define CS4272_DAC_CHA_VOL_VOLUME(x)		(uint8_t)(((x) & 0x7F) << 0)

// Section 8.5 DAC Channel B volume
#define CS4272_DAC_CHB_VOL			(uint8_t)0x05
#define CS4272_DAC_CHB_VOL_MUTE			(uint8_t)0x80
#define CS4272_DAC_CHB_VOL_VOLUME(x)		(uint8_t)(((x) & 0x7F) << 0)

// Section 8.6 ADC Control
#define CS4272_ADC_CTRL				(uint8_t)0x06
#define CS4272_ADC_CTRL_DITHER			(uint8_t)0x20
#define CS4272_ADC_CTRL_SER_FORMAT		(uint8_t)0x10
#define CS4272_ADC_CTRL_MUTE(x)			(uint8_t)(((x) & 0x03) << 2)
#define CS4272_ADC_CTRL_HPF(x)			(uint8_t)(((x) & 0x03) << 0)

// Section 8.7 Mode Control 2
#define CS4272_MODE_CTRL2			(uint8_t)0x07
#define CS4272_MODE_CTRL2_LOOP			(uint8_t)0x10
#define CS4272_MODE_CTRL2_MUTE_TRACK		(uint8_t)0x08
#define CS4272_MODE_CTRL2_CTRL_FREEZE		(uint8_t)0x04
#define CS4272_MODE_CTRL2_CTRL_PORT_EN		(uint8_t)0x02
#define CS4272_MODE_CTRL2_POWER_DOWN		(uint8_t)0x01

// Section 8.8 Chip ID
#define CS4272_CHIP_ID				(uint8_t)0x08
#define CS4272_CHIP_ID_PART(x)			(uint8_t)(((x) & 0x0F) << 4)
#define CS4272_CHIP_ID_REV(x)			(uint8_t)(((x) & 0x0F) << 0)


#define CS4272_RESET_PIN 22

bool AudioControlCS4272_192k::enable(void)
{
	Wire.begin();
	delay(5);
	initLocalRegs();

	// Setup Reset pin
	pinMode(CS4272_RESET_PIN, OUTPUT);

	// Drive pin low
	digitalWriteFast(CS4272_RESET_PIN, LOW);
	delay(1);

	// Release Reset
	digitalWriteFast(CS4272_RESET_PIN, HIGH);
	delay(2);

	// Set power down and control port enable as spec'd in the 
	// datasheet for control port mode
	write(CS4272_MODE_CTRL2, CS4272_MODE_CTRL2_POWER_DOWN
		| CS4272_MODE_CTRL2_CTRL_PORT_EN);

	// Wait for further setup
	delay(1);

	// Set ratio select for MCLK=512*LRCLK (BCLK = 64*LRCLK), and master mode, I2S
	// https://forum.pjrc.com/index.php?threads/73960/
	write(CS4272_MODE_CONTROL, CS4272_MC_FUNC_MODE(CS4272_RATIO_QUAD) | CS4272_MC_RATIO_SEL(2) | CS4272_MC_MASTER_SLAVE |
		CS4272_MC_SERIAL_FORMAT(1));
	//write(CS4272_MODE_CONTROL, CS4272_MC_FUNC_MODE(CS4272_RATIO_QUAD) | CS4272_MC_RATIO_SEL(0) | CS4272_MC_MASTER_SLAVE | 
    //	CS4272_MC_SERIAL_FORMAT(1));
	write(CS4272_ADC_CTRL, CS4272_ADC_CTRL_SER_FORMAT); // Set ADC I2S format

	delay(10);
	
	// Release power down bit to start up codec
	// TODO: May need other bits set in this reg
	write(CS4272_MODE_CTRL2, CS4272_MODE_CTRL2_CTRL_PORT_EN);
	
	// Wait for everything to come up
	delay(10);


	return true;
}

bool AudioControlCS4272_192k::volumeInteger(unsigned int n)
{
	unsigned int val = 0x7F - (n & 0x7F);
	write(CS4272_DAC_CHA_VOL,CS4272_DAC_CHA_VOL_VOLUME(val));
	write(CS4272_DAC_CHB_VOL,CS4272_DAC_CHB_VOL_VOLUME(val));
	return true;
}

bool AudioControlCS4272_192k::volume(float left, float right)
{
	unsigned int leftInt,rightInt;

	leftInt = left*127 + 0.499;
	rightInt = right*127 + 0.499;

	unsigned int val = 0x7F - (leftInt & 0x7F);
	write(CS4272_DAC_CHA_VOL,CS4272_DAC_CHA_VOL_VOLUME(val));
	
	val = 0x7F - (rightInt & 0x7F);
	write(CS4272_DAC_CHB_VOL,CS4272_DAC_CHB_VOL_VOLUME(val));

	return true;
}

bool AudioControlCS4272_192k::dacVolume(float left, float right)
{
	return volume(left,right);
}

bool AudioControlCS4272_192k::muteOutput(void)
{
	write(CS4272_DAC_CHA_VOL, 
		regLocal[CS4272_DAC_CHA_VOL] | CS4272_DAC_CHA_VOL_MUTE);

	write(CS4272_DAC_CHB_VOL, 
		regLocal[CS4272_DAC_CHB_VOL] | CS4272_DAC_CHB_VOL_MUTE);

	return true;
}

bool AudioControlCS4272_192k::unmuteOutput(void)
{
	write(CS4272_DAC_CHA_VOL, 
		regLocal[CS4272_DAC_CHA_VOL] & ~CS4272_DAC_CHA_VOL_MUTE);

	write(CS4272_DAC_CHB_VOL, 
		regLocal[CS4272_DAC_CHB_VOL] & ~CS4272_DAC_CHB_VOL_MUTE);

	return true;
}

bool AudioControlCS4272_192k::muteInput(void)
{
	uint8_t val = regLocal[CS4272_ADC_CTRL] | CS4272_ADC_CTRL_MUTE(3);
	write(CS4272_ADC_CTRL,val);
	return true;
}

bool AudioControlCS4272_192k::unmuteInput(void)
{
	uint8_t val = regLocal[CS4272_ADC_CTRL] & ~CS4272_ADC_CTRL_MUTE(3);
	write(CS4272_ADC_CTRL,val);
	return true;
}

bool AudioControlCS4272_192k::enableDither(void)
{
	uint8_t val = regLocal[CS4272_ADC_CTRL] | CS4272_ADC_CTRL_DITHER;
	write(CS4272_ADC_CTRL,val);
	return true;
}

bool AudioControlCS4272_192k::disableDither(void)
{
	uint8_t val = regLocal[CS4272_ADC_CTRL] & ~CS4272_ADC_CTRL_DITHER;
	write(CS4272_ADC_CTRL,val);
	return true;
}


bool AudioControlCS4272_192k::write(unsigned int reg, unsigned int val)
{
	// Write local copy first
	if(reg > 7)
		return false;

	regLocal[reg] = val;

	Wire.beginTransmission(CS4272_ADDR);
	Wire.write(reg & 0xFF);
	Wire.write(val & 0xFF);
	Wire.endTransmission();
	return true;
}


// Initialize local registers to CS4272 reset status
void AudioControlCS4272_192k::initLocalRegs(void)
{
	regLocal[CS4272_MODE_CONTROL] = 0x00;
	regLocal[CS4272_DAC_CONTROL] = CS4272_DAC_CTRL_AUTO_MUTE;
	regLocal[CS4272_DAC_VOL] = CS4272_DAC_VOL_SOFT_RAMP(2) | CS4272_DAC_VOL_ATAPI(9);
	regLocal[CS4272_DAC_CHA_VOL] = 0x00;
	regLocal[CS4272_DAC_CHB_VOL] = 0x00;
	regLocal[CS4272_ADC_CTRL] = 0x00;
	regLocal[CS4272_MODE_CTRL2] = 0x00;
}

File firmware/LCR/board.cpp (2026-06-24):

#include "board.h"


DMAMEM uint16_t framebuffer[SCREEN_WIDTH * SCREEN_HEIGHT];

Board board;

void Board::init() {
  pinMode(RANGE_SEL_0_PIN, OUTPUT);
  pinMode(RANGE_SEL_1_PIN, OUTPUT);
  pinMode(PGA_V_0_PIN, OUTPUT);
  pinMode(PGA_V_1_PIN, OUTPUT);
  pinMode(PGA_I_0_PIN, OUTPUT);
  pinMode(PGA_I_1_PIN, OUTPUT);

  pinMode(FAN_PIN, OUTPUT);
  pinMode(FAN_PIN, OUTPUT);

  enter_button.begin();
  up_button.begin();
  down_button.begin();
  select_button_0.begin();
  select_button_1.begin();
  select_button_2.begin();
  select_button_3.begin();

  setLCRRange(LCR_RANGE_100);
  setPGAGainV(PGA_GAIN_1);
  setPGAGainI(PGA_GAIN_1);

  temp_sensor.begin();
  temp_sensor.writeConfig(MCP9800::ADC_RES_12BITS);

  tft.begin(14000000);
  tft.setRotation(3);
  tft.setFrameBuffer(framebuffer);
  tft.useFrameBuffer(true);
  tft.updateChangedAreasOnly(true);

  ts.begin();
  ts.setRotation(1);

  ts_ignoreuntil = 0;
  ts_state = false;
  
}


void Board::setLCRRange(uint8_t range) {
  board_range = range & 0x03;
  digitalWrite(RANGE_SEL_0_PIN, (board_range >> 0) & 0x01);
  digitalWrite(RANGE_SEL_1_PIN, (board_range >> 1) & 0x01);
}

void Board::setPGAGainV(uint8_t gain) {
  board_gain_v = gain & 0x03;
  digitalWrite(PGA_V_0_PIN, (board_gain_v >> 0) & 0x01);
  digitalWrite(PGA_V_1_PIN, (board_gain_v >> 1) & 0x01);
}

void Board::setPGAGainI(uint8_t gain) {
  board_gain_i = gain & 0x03;
  digitalWrite(PGA_I_0_PIN, (board_gain_i >> 0) & 0x01);
  digitalWrite(PGA_I_1_PIN, (board_gain_i >> 1) & 0x01);
}

bool Board::increaseVGain() {
  if (board_gain_v < PGA_GAIN_NUM-1) {
    setPGAGainV(board_gain_v + 1);
    return true;
  }
  return false;
}

bool Board::decreaseVGain() {
  if (board_gain_v > 0) {
    setPGAGainV(board_gain_v - 1);
    return true;
  }
  return false;
}

bool Board::increaseIGain() {
  if (board_gain_i < PGA_GAIN_NUM-1) {
    setPGAGainI(board_gain_i + 1);
    return true;
  }
  return false;
}

bool Board::decreaseIGain() {
  if (board_gain_i > 0) {
    setPGAGainI(board_gain_i - 1);
    return true;
  }
  return false;
}

bool Board::increaseLCRRange() {
  if (board_range < LCR_RANGE_NUM-1) {
    setLCRRange(board_range + 1);
    return true;
  }
  return false;
}

bool Board::decreaseLCRRange() {
  if (board_range > 0) {
    setLCRRange(board_range - 1);
    return true;
  }
  return false;
}

float Board::getTemperature() {
  return temp_sensor.readTempC16(MCP9800::AMBIENT) / 16.0;
}

uint16_t boundedMap(uint16_t x, uint16_t a1, uint16_t a2, uint16_t b1, uint16_t b2) {
  if (x < a1) return b1;
  if (x > a2) return b2;
  return map(x, a1, a2, b1, b2); 
}

bool Board::tsPressed(long unsigned int debounce_ms) {
  if (tft.asyncUpdateActive()) return false;
  if (millis() < ts_ignoreuntil) return false;

  bool curr_state = ts.touched();

  if (curr_state == ts_state) return false;
  
  ts_ignoreuntil = millis() + debounce_ms;
  ts_state = curr_state;
  
  if (curr_state) {
    TS_Point p = ts.getPoint();
    ts_x = boundedMap(p.x, TS_X_MIN, TS_X_MAX, 0, SCREEN_WIDTH);
    ts_y = boundedMap(p.y, TS_Y_MIN, TS_Y_MAX, 0, SCREEN_HEIGHT);
    return true;
  } else {
    return false;
  }

}

void Board::waitForInput() {
  while (!enter_button.pressed() && !tsPressed()) {
    yield();
  }
}

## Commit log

2026-03-22 KiCAD creation
    [codec.kicad_sch, lcr.kicad_pcb, lcr.kicad_sch]
2026-04-11 PCB Files
    [codec.kicad_sch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]
2026-04-11 Rolling PCB back to autosaved version
    [lcr.kicad_pcb]
2026-04-11 top level pcb routing
    [lcr.kicad_pcb, lcr.kicad_sch, power.kicad_sch]
2026-04-13 Redoing whole layout
    [codec.kicad_sch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]
2026-04-14 pcb layout
    [lcr-B_Cu.gbr, lcr-B_Mask.gbr, lcr-B_Paste.gbr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]
2026-04-21 Rev 1 PCB files
    [codec.kicad_sch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]
2026-04-22 Initial firmware commit
    [lcr.kicad_pcb, teensy.kicad_sch]
2026-04-23 buzzer update and test
    [lcr.kicad_pcb]
2026-04-29 Test code
    [lcr.kicad_pcb, lcr.kicad_sch, power.kicad_sch]
2026-05-10 Self calibration
    Self calibration largely finished and tested.
    Save and load of calibration implementation finalized.
    Selection/linear interpolation of calibration data
2026-05-13 Calibration + impedance functions
2026-05-15 Float printing
    Added class for formatted float printing with metric prefixes and fixed # of digits
    [LCR.ino, autorange.cpp, constants.h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]
2026-05-22 Menu test code
    [lcr-B_Cu.gbr, lcr-B_Mask.gbr, lcr-B_Paste.gbr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]
2026-05-26 Menu interaction with system
    Also fixed a nasty little bug with function pointers inside the Complex class in the calibration struct. Calling print on the calibration data values without first copying the calibration data to a different struct crashed the program. Fixed by just reading into a dummy array and then copying to a different array, but the real fix would be to not just do a raw memory read on the calibration data
    [LCR.ino, board.cpp, calibration.cpp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]
2026-06-03 LCR parameter printing code
2026-06-07 Log printing code
2026-06-09 Cal display code
    Some more sloppy code but it works.
    More than pretty enough for a procedure that I hope is not used much. The probe cal is the nicest, which reflects that being the most commonly used
    [calibration.cpp, display.cpp]
2026-06-18 Frequency selector
    Added support for holding down button and showing selected digit. Can now exit selector mode and menu bar updates with appropriate frequency
2026-06-27 Multiple probe type cals
2026-06-27 Firmware reorg + probe toggle
2026-06-28 moving average filter
2026-07-22 Fixed major bug in sweep measurements
    The TIA did not autorange when running a sweep. It was stuck on whatever range the system was in when the sweep tab was opened. This led to inconsistent (and incorrect) results
    [autorange.cpp, sweep.cpp]
2026-07-29 cad folder
    [.step, PCB.step, TFT.step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]
2026-08-01 front panel CAD work
    [2.8 TFT Module.SLDASM, 2.8 TFT Module.stp, TFT.step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]
2026-08-02 up down enter buttons
    [arrow_cap.SLDPRT, button.SLDPRT, enter_cap.SLDPRT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]
2026-08-11 CAD files
2026-08-11 Up + Down selector cutouts
    [front_panel.SLDPRT]
2026-08-12 cad progress
    [front_panel.SLDPRT, shell.SLDPRT]
2026-08-15 cad fles + menu PCB
    [back_panel.SLDPRT, front_panel.SLDPRT, menu_PCB.SLDPRT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]
2026-09-07 changes from front panel test print
    [back_panel.SLDPRT, front_panel.3MF, front_panel.SLDPRT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]
2026-09-08 selector board
    [selector_board-F_Cu.dxf, selector_board.kicad_pcb, selector_board.kicad_sch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]
2026-10-22 Minor pin changes + sign bug fix in sweep
